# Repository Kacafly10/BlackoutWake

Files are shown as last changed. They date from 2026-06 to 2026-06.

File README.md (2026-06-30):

# BlackoutWake

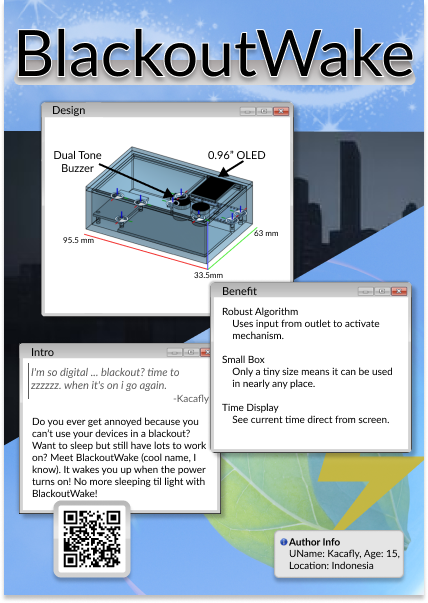
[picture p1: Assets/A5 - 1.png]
pr

>### I'm so digital ... blackout? time to zzzzzz. when it's on i go again.
Blackouts are a big nuisance to us digital people. When everything shuts down, our best bet would be to catch up to our sleeping backlog. _"What about if we oversleep?"_ well, BlackoutWake helps by informing you when the power turns on.

BlackoutWake was Ideated in a saga of blackouts cutting internet, charging and every other digital Item. I wanted to sleep, but still get all my fallout projects done. It uses a **AC to DC converter** to turn on a **Raspberry Pi pico** when electricity flows from the plug. The pico drives 2 **Buzzers** and displays through **oled** time when you woke up--or more accurately ~current time--from queries to an **RTC**. Let's sleep! Well, me, at very least.

## Wire

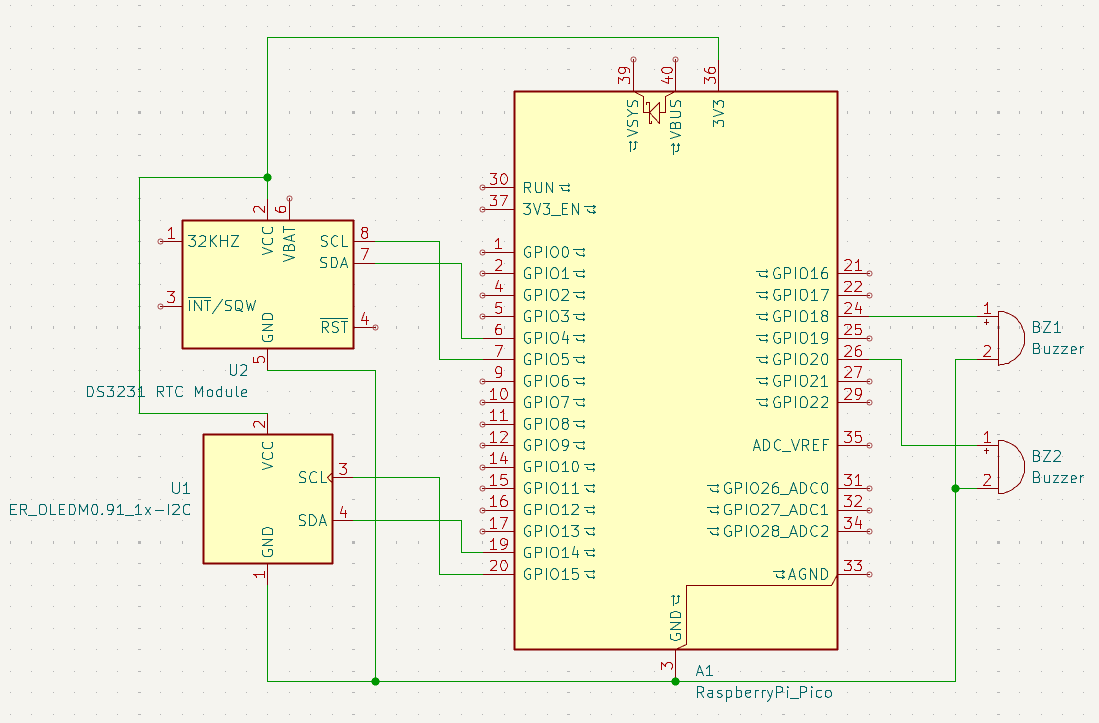
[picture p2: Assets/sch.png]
wd


## 3d

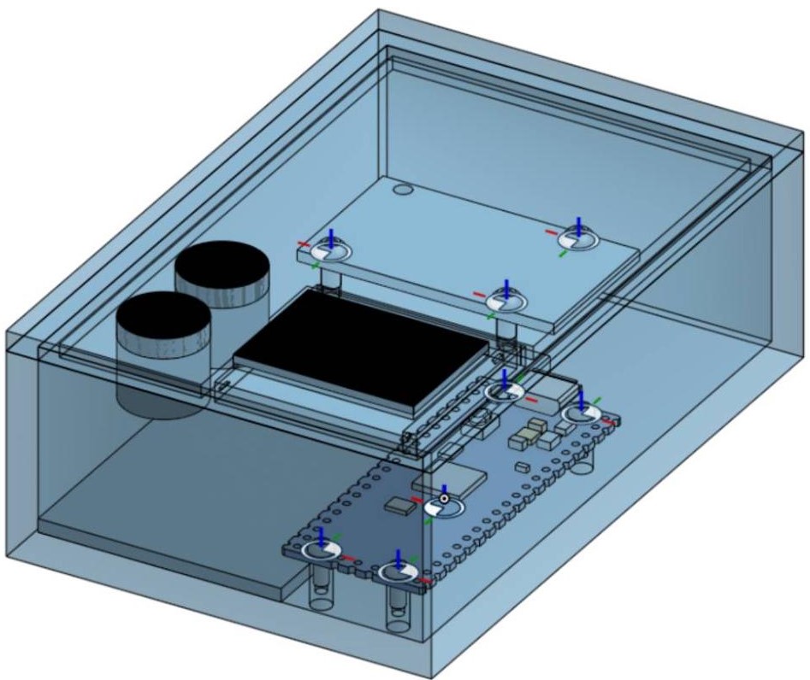
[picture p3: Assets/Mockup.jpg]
Mockup

`Mockup`

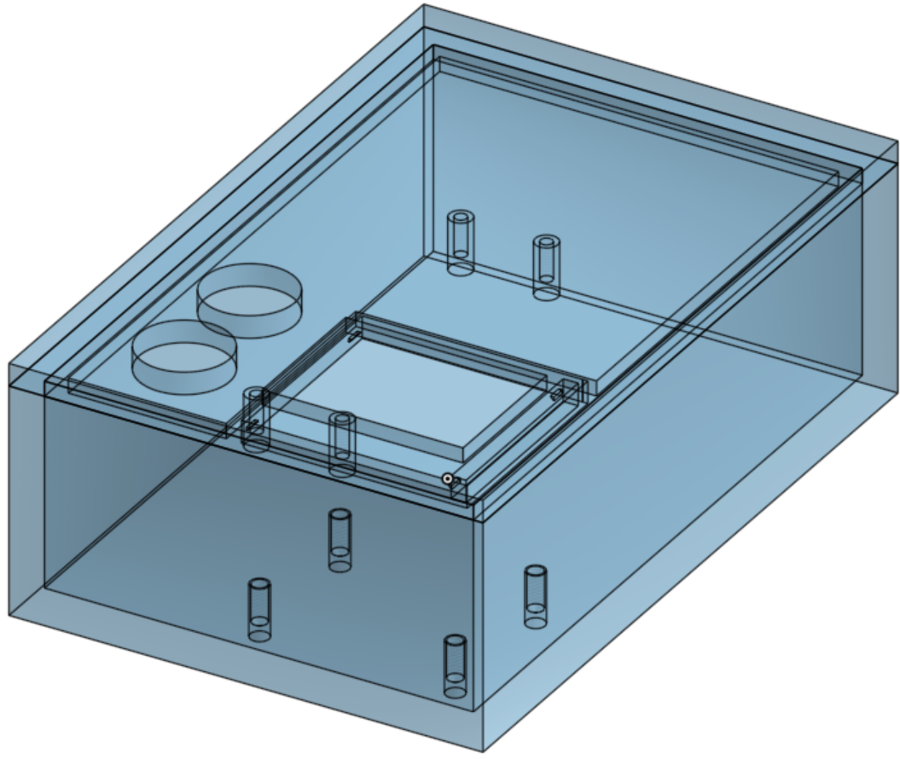
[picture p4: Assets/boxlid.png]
Box + Lid

`Box & Lid`

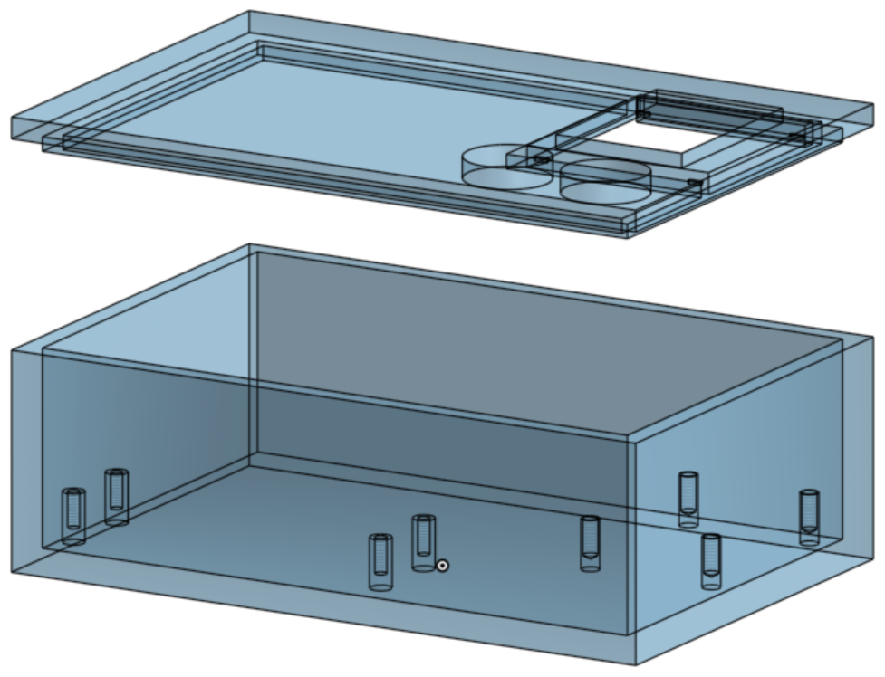
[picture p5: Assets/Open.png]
Opened

`Open View`

[onshape](https://cad.onshape.com/documents/0ff01360ea1e6058d91f01e5/w/d01b925eefa85f8894e07011/e/78fdfa6156e56ede7d53773d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)

## Assembly
1. Solder or join all electronic parts (see Wire for connections)
2. Adhese ac-dc to edge of box
3. Screw in rtc and pico
4. Clip in oled to lid
8. Slot and optionally adhese each buzzer

## Program
1. Turn on buzz tone when power is supplied to vsys
2. Get time from RTC
3. Turn off buzzes after 5 minutes

## Bill Of Materials
| Name | Qty | | Price/One | Price/Total | Notes |
| --- | --- | --- | --- | --- | --- |
| Pi pico | 1 | Pcs | $2.02 | $2.02 | https://www.aliexpress.com/item/1005007104120926.html |
| rtc module | 1 | Pcs | $2.07 | $2.07 | https://www.aliexpress.com/item/1005010675331392.html |
| ac - dc converter | 1 | Pcs | $0.86 | $0.86 | https://www.aliexpress.com/item/1005009215532545.html |
| Oled Module .96 inch | 1 | Pcs | $1.15 | $1.15 | https://www.aliexpress.com/item/1005009993690787.html |
| buzzer | 1 | Lot@5Pcs | $0.77 | $0.77 | https://www.aliexpress.com/item/32856257256.html |
| box | 1 | Pcs | $3.95 | $3.95 | https://jlc3dp.com/3d-printing-quote |
| lid | 1 | Pcs | $1.55 | $1.55 | https://jlc3dp.com/3d-printing-quote |
| Cable + plug | 1 | Set | $0.96 | $0.96 | https://www.aliexpress.com/item/1005007805525495.html |
| Total | | | | $13.33 | | 

[General](/bom.csv)

## Credits
RPi
    Pi pico 3D File

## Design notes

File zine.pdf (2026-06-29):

# BlackoutWake

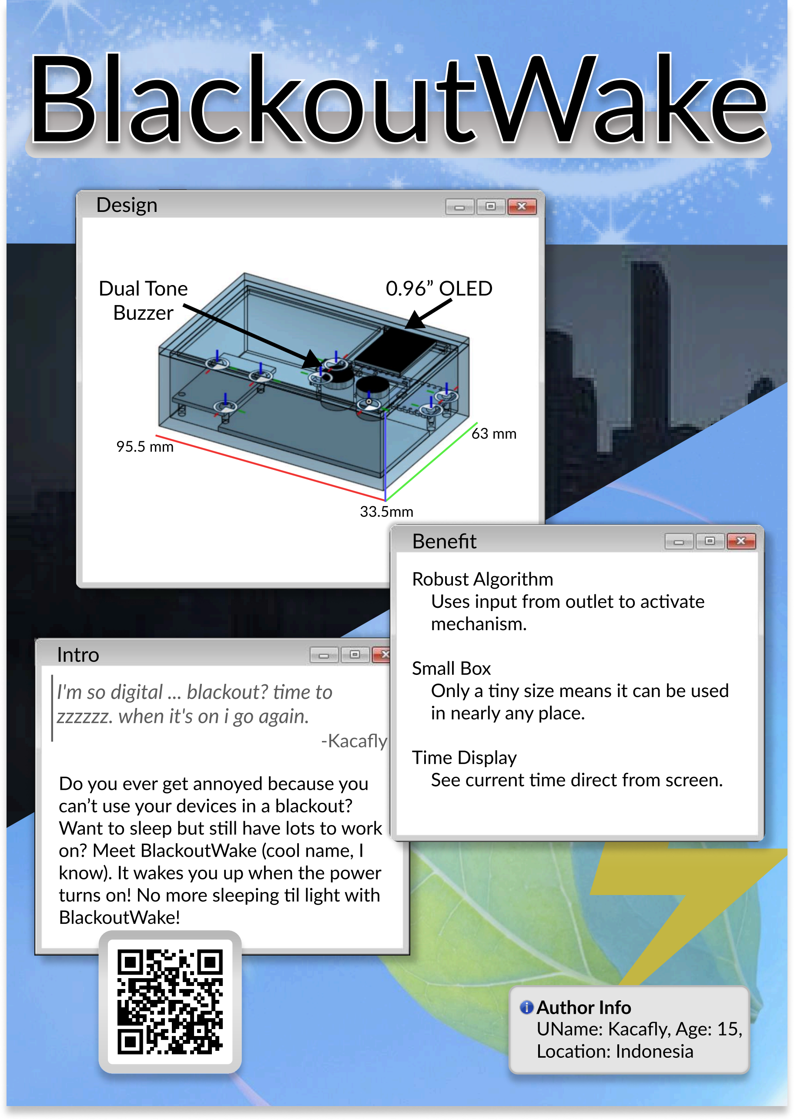
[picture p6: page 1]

Design

Dual Tone
Buzzer

### 0.96” OLED

63 mm

33.5mm

Benefit

Robust Algorithm
Uses input from outlet to activate mechanism.

Small Box
Only a tiny size means it can be used in nearly any place.

Time Display
See current time direct from screen.

Intro

I'm so digital ... blackout? time to

zzzzzz. when it's on i go again.

-Kacafly

Do you ever get annoyed because you can’t use your devices in a blackout? Want to sleep but still have lots to work on? Meet BlackoutWake (cool name, I know). It wakes you up when the power

turns on! No more sleeping til light with BlackoutWake!

95.5 mm

Author Info
UName: Kacafly, Age: 15,
Location: Indonesia

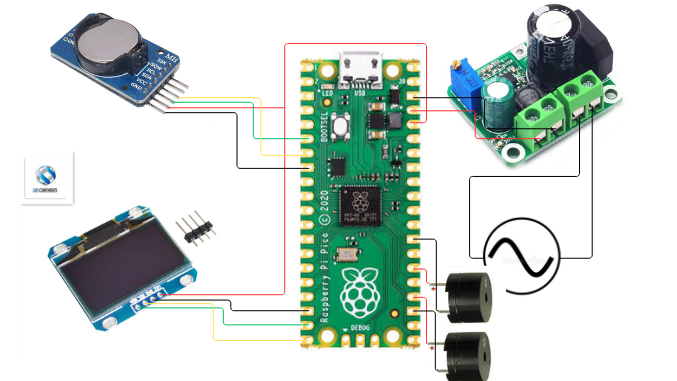
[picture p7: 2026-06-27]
Assets/wird.png

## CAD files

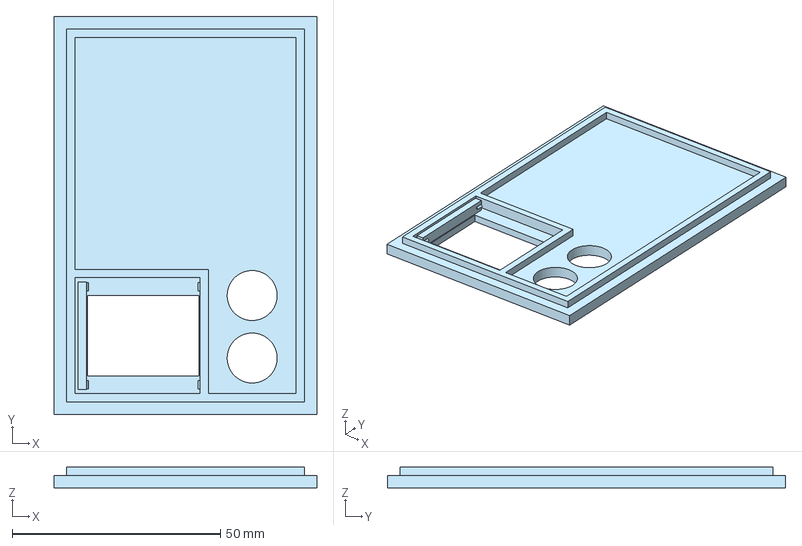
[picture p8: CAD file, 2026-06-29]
3d/Cover.step
63.0 x 95.5 x 5.00 mm

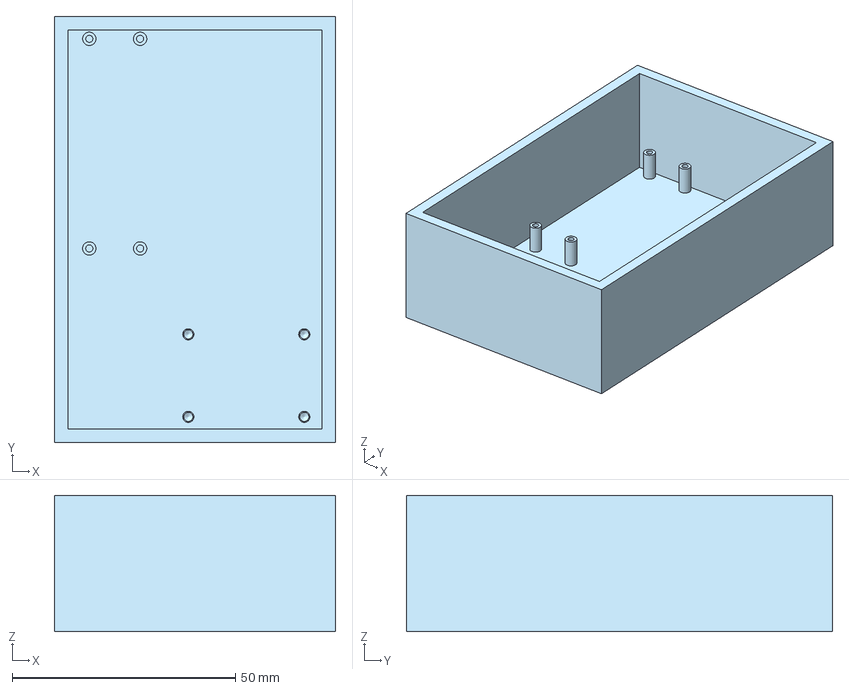
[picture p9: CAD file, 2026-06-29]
3d/Box.step
63.0 x 95.5 x 30.5 mm

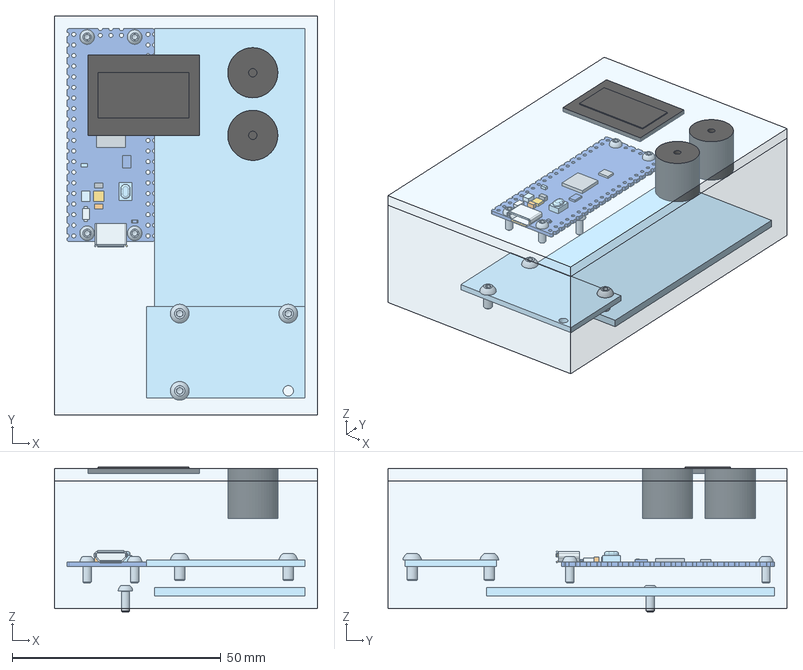
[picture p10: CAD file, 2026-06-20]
3d/Mockup.step
63.0 x 95.5 x 34.6 mm
Socket button head screw M2.5x0.45 x 5 x 3
Socket button head screw M2x0.4 x 5 x 6
PICO_WINBOND.STEP
PICO_DIODES.STEP
PICO_REF_USB.STEP x 5
PICO_REF_SWITCH.STEP
PICO_REF_MICROCONTROLLER.STEP
PICO_REF_LED.STEP
PICO_RICHTEK.STEP
PICO_REF_ONSEMI.STEP
PICO_REF_BOARD.STEP
PICO_MURATA.STEP
PICO_AEL.STEP
PICO_MURATA.STEP_1
PICO_BOURNS.STEP

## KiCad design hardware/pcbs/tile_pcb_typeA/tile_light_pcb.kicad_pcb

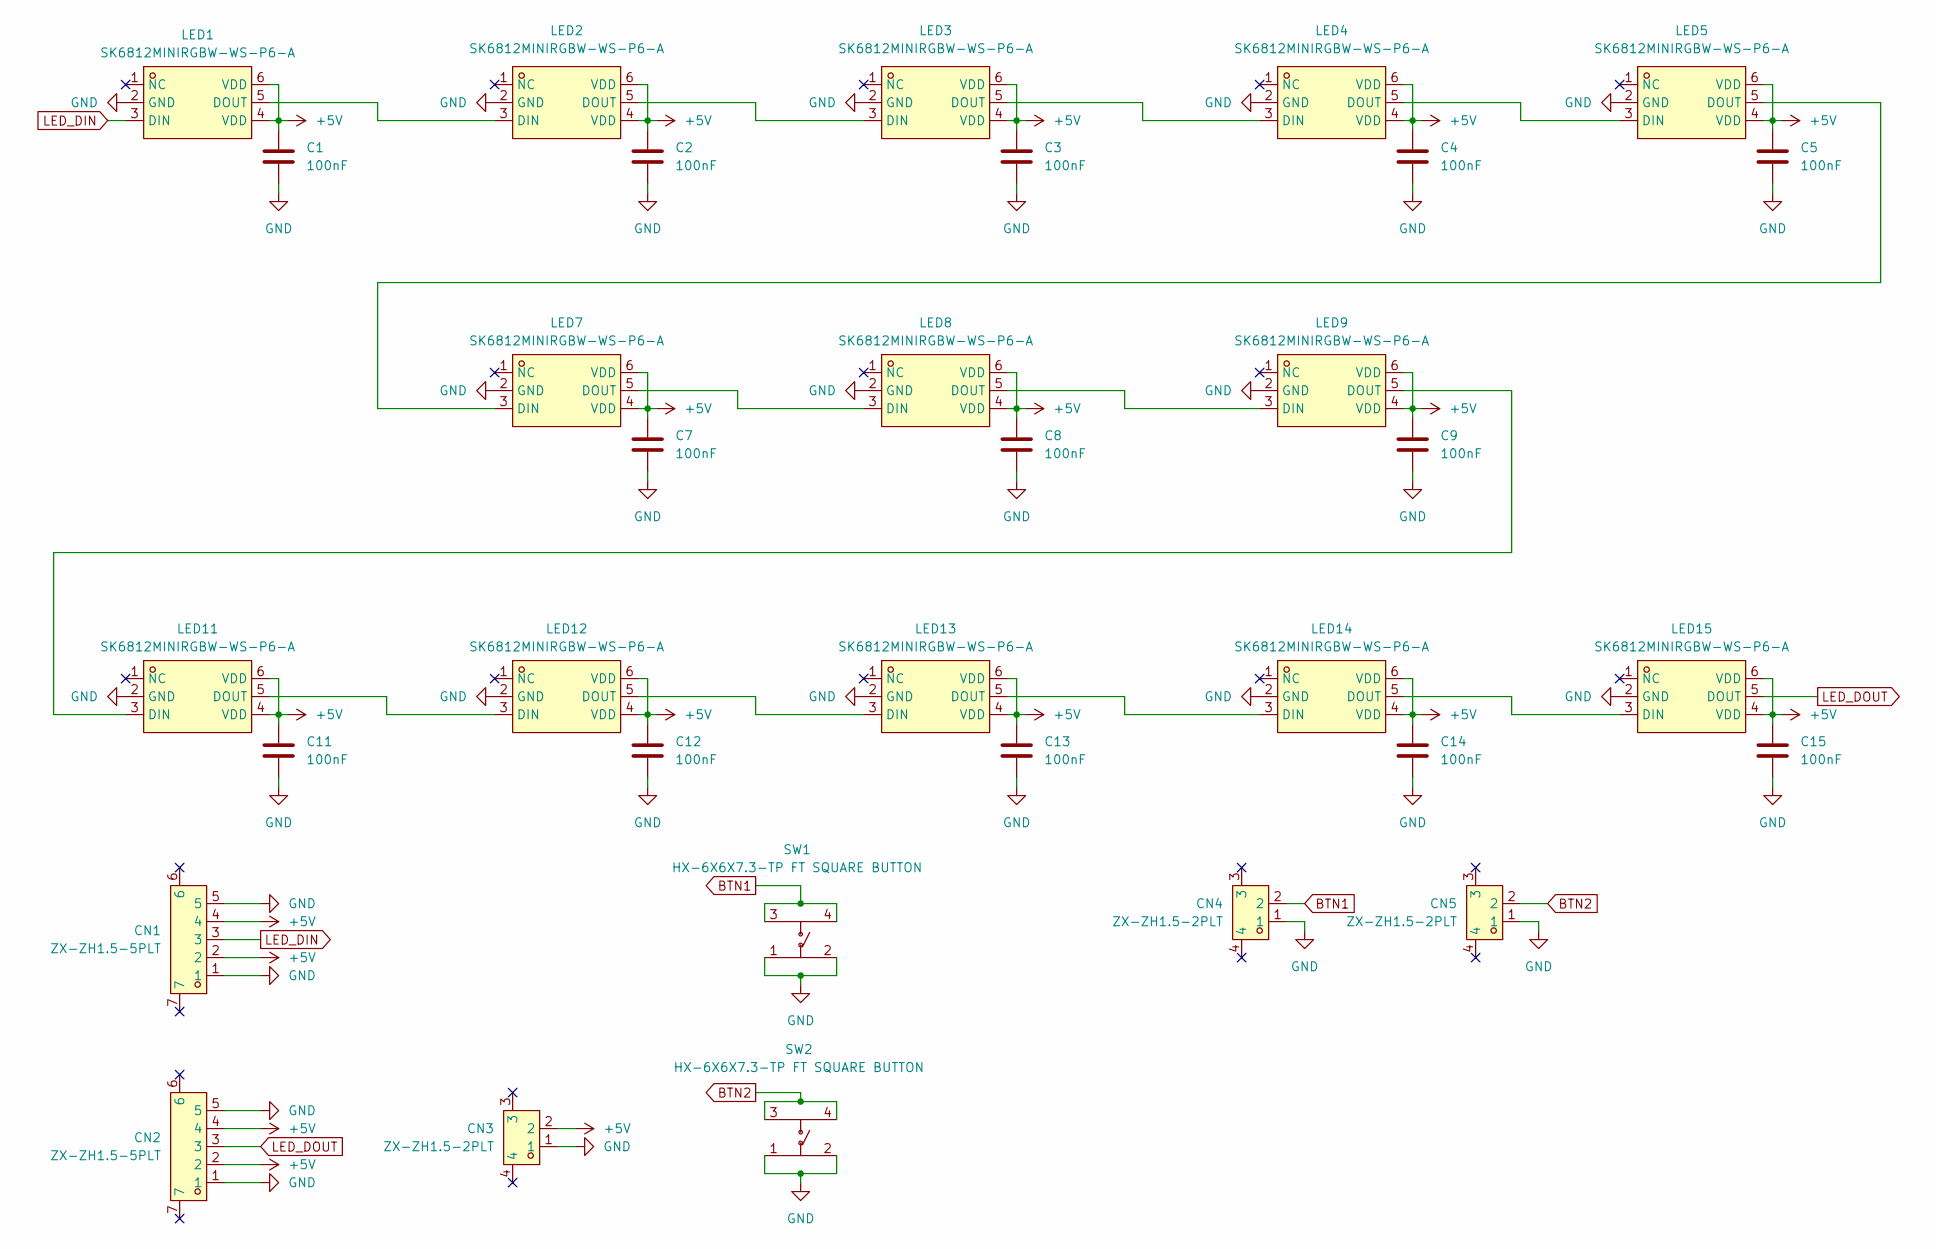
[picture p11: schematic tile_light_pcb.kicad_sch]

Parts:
C1, C2, C3, C4, C5, C7, C8, C9, C11, C12, C13, C14, C15: 100nF; C_0402_1005Metric; LCSC Part # C60474
CN1, CN2: ZX-ZH1.5-5PLT; CONN-SMD_5P-P1.50_ZX-ZH1.5-5PLT; LCSC Part C19272417
CN3, CN4, CN5: ZX-ZH1.5-2PLT; CONN-SMD_2P-P1.50_ZX-ZH1.5-2PLT; LCSC Part C19272414
LED1, LED2, LED3, LED4, LED5, LED7, LED8, LED9, LED11, LED12, LED13, LED14, LED15: SK6812MINIRGBW-WS-P6-A; LED-SMD_6P-L3.5-W3.5_SK6812MINIRGBW-WS-P6-A; MPN SK6812MINIRGBW-WS-P6-A; LCSC Part C7423106
SW1, SW2: HX-6X6X7.3-TP FT SQUARE BUTTON; SW-SMD_4P-L6.0-W6.0-P4.50-LS9.0-H7.3; MPN HX-6x6x7.3-TP FT square button; LCSC Part C49234152

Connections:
+5V: C1.2, C2.2, C3.2, C4.2, C5.2, C7.2, C8.2, C9.2, C11.2, C12.2, C13.2, C14.2, C15.2, CN1.2, CN1.4, CN2.2, CN2.4, CN3.2, LED1.4 (VDD), LED1.6 (VDD), LED2.4 (VDD), LED2.6 (VDD), LED3.4 (VDD), LED3.6 (VDD), LED4.4 (VDD), LED4.6 (VDD), LED5.4 (VDD), LED5.6 (VDD), LED7.4 (VDD), LED7.6 (VDD), LED8.4 (VDD), LED8.6 (VDD), LED9.4 (VDD), LED9.6 (VDD), LED11.4 (VDD), LED11.6 (VDD), LED12.4 (VDD), LED12.6 (VDD), LED13.4 (VDD), LED13.6 (VDD), LED14.4 (VDD), LED14.6 (VDD), LED15.4 (VDD), LED15.6 (VDD)
BTN1: CN4.2, SW1.3, SW1.4
BTN2: CN5.2, SW2.3, SW2.4
GND: C1.1, C2.1, C3.1, C4.1, C5.1, C7.1, C8.1, C9.1, C11.1, C12.1, C13.1, C14.1, C15.1, CN1.1, CN1.5, CN2.1, CN2.5, CN3.1, CN4.1, CN5.1, LED1.2 (GND), LED2.2 (GND), LED3.2 (GND), LED4.2 (GND), LED5.2 (GND), LED7.2 (GND), LED8.2 (GND), LED9.2 (GND), LED11.2 (GND), LED12.2 (GND), LED13.2 (GND), LED14.2 (GND), LED15.2 (GND), SW1.1, SW1.2, SW2.1, SW2.2
LED_DIN: CN1.3, LED1.3 (DIN)
LED_DOUT: CN2.3, LED15.5 (DOUT)
unnamed: LED1.5 (DOUT), LED2.3 (DIN)
unnamed: LED2.5 (DOUT), LED3.3 (DIN)
unnamed: LED3.5 (DOUT), LED4.3 (DIN)
unnamed: LED4.5 (DOUT), LED5.3 (DIN)
unnamed: LED5.5 (DOUT), LED7.3 (DIN)
unnamed: LED7.5 (DOUT), LED8.3 (DIN)
unnamed: LED8.5 (DOUT), LED9.3 (DIN)
unnamed: LED9.5 (DOUT), LED11.3 (DIN)
unnamed: LED11.5 (DOUT), LED12.3 (DIN)
unnamed: LED12.5 (DOUT), LED13.3 (DIN)
unnamed: LED13.5 (DOUT), LED14.3 (DIN)
unnamed: LED14.5 (DOUT), LED15.3 (DIN)

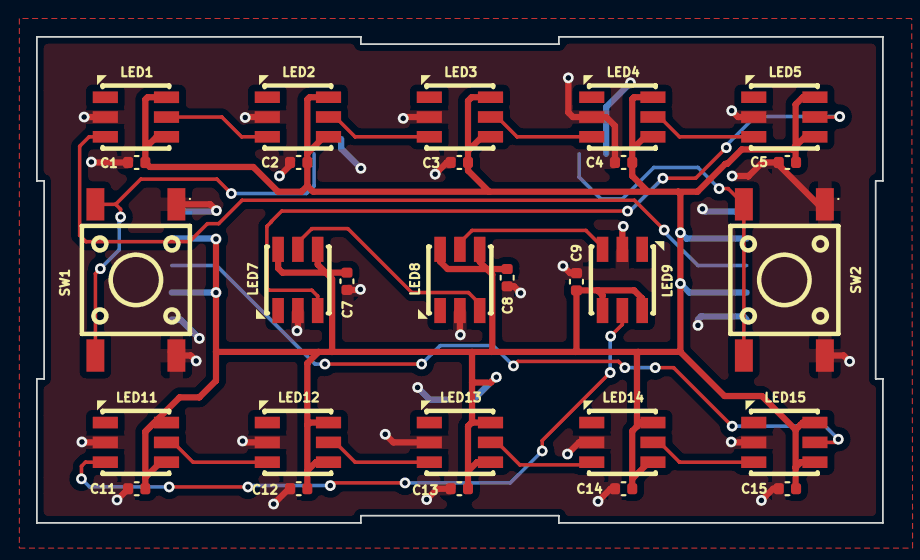
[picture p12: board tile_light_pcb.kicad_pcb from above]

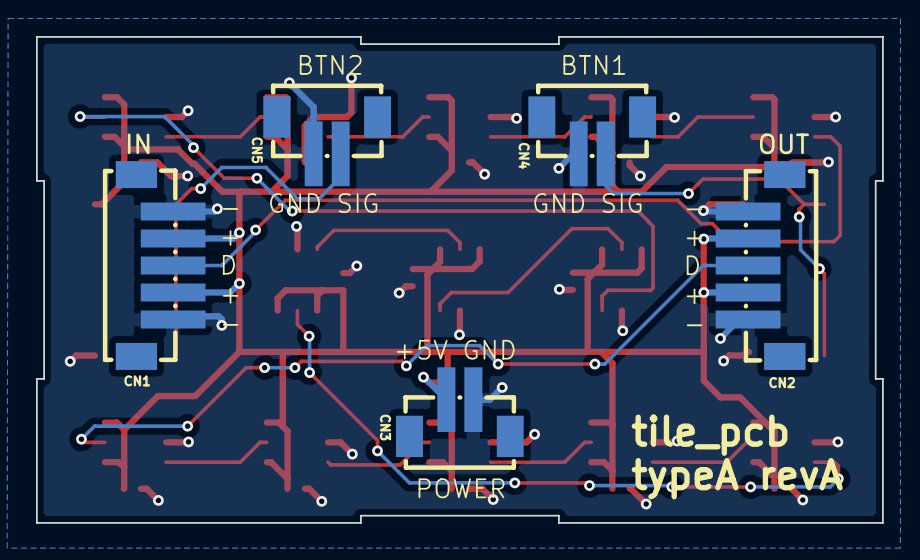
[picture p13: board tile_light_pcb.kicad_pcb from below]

Board: 2 copper layers, 47.0 x 27.0 mm, 33 parts (5 on the bottom side), 18 nets.

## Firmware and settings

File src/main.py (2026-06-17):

from machine import Pin, PWM, I2C
import ssd1306

f1 = PWM(Pin(1), freq=2000, duty_u16=32768/2)
f2 = PWM(Pin(2), freq=5000, duty_u16=32768/2)

clkiic = I2C(0)

disiic = I2C(1, sdaPin=Pin(14), sclPin=Pin(15))
dis = ssd1306.SSD1306_I2C(128, 64, disiic)
dis.poweron()

buf = bytearray(7)
buf_old = bytearray(7)

clkiic.writeto(0x68, 7)
clkiic.readfrom(0x68, buf_old)

while True:
    clkiic.writeto(0x68, 7)
    clkiic.readfrom(0x68, buf)
    buf_t = str.from_bytes(buf, 'little')
    time = f"{str(buf_t[2]):02}:{str(buf_t[1]):02}:{str(buf_t[0]):02}"
    date = f"{str(buf_t[4]):02}/{str(buf_t[5]):02}/{str(buf_t[6]):02}"

    dis.text(time,0,0,1)
    dis.text(date,0,0,2)
    dis.show()

    if buf[1] > buf_old[1] + 5:
        f1.duty_u16(0)
        f2.duty_u16(0)
    
    
    

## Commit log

2026-06-17 fix driver initialization
2026-06-17 add 3d of pack
    [b.step]
2026-06-26 xlsx to CSv
    [bom.csv, bom.xlsx]
2026-06-27 fix bom
    [bom.csv]
2026-06-27 fix md
    [bom.csv]
2026-06-27 desc, spec and bom
2026-06-29 Individual STEPs and revised zine
    [Box.step, Cover.step]
2026-06-30 add EDA Sch
    [bw.kicad_pcb, bw.kicad_sch]
2026-06-30 Change wiring image to schematic diagram
    Updated the wiring diagram image in the README.
